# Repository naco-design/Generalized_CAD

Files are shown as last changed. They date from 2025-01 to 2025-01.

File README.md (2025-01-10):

# Generalized_CAD
Generalized CAD Assistant Device, This is a programmable macro pad!
\
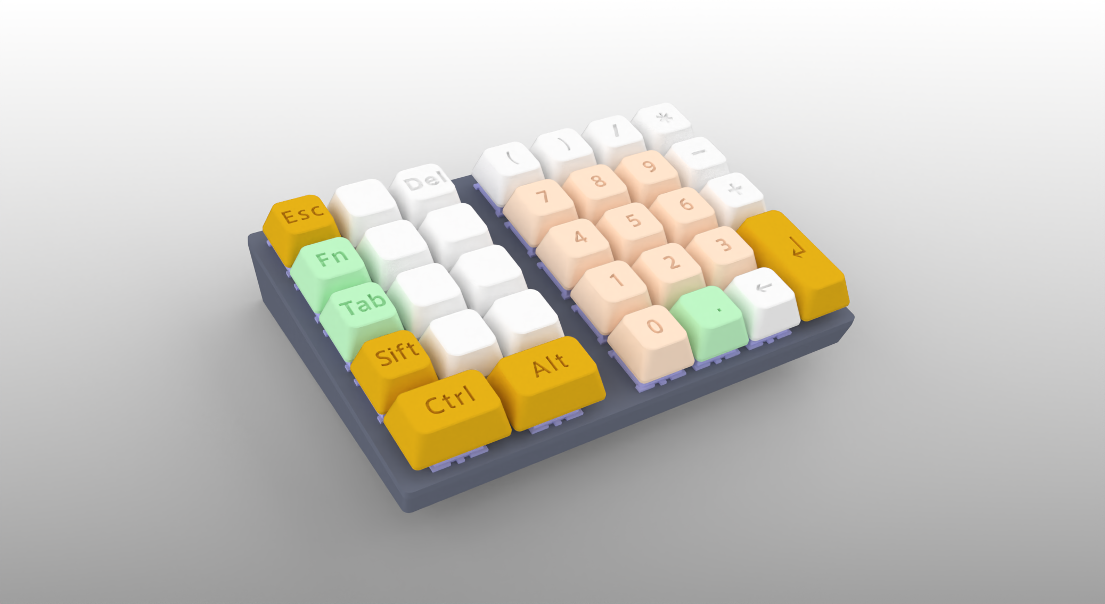
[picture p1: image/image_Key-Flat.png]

キーの上面がFlatになるデータの場合のイメージ

## 汎用型CAD（CADアシスタントデバイス）
CAD作業を行いやすくするための補助デバイス（マクロパッド）の制作データです。\
3Dプリントした部品とキースイッチやダイオード、ProMicro、WS2812などを組み合わせます。\
Vialに対応したファームウェアでキー設定をカスタマイズすることが可能です。
\
\
以下のデータを順次公開します。
* 3Dプリント用STLファイル（ケース、キーキャップ）
* VIAL対応ファームウェア
* 部品のリスト
* 回路の配線や組み立ての手順

## 開発にあたって
* 右手はマウスを握ったまま、左手で数値やショートカットを入力したい。
* 基盤をおこすのはハードルが高いので、回路は手配線で組む。
* カスタマイズしやすいように、3Dプリンターで製造したい。
* 大きさは、はがきサイズ（148*100mm）程度を目指す。

## 部品
### 3Dプリント用STL/STEPファイル（ケース、キーキャップ）
[ケース](Cases)\
Case_v2025-01.stl\
LED-Plate.stl\
ProMicro_Lock.stl\
BackPanel.stl\
レーザー加工の場合は BackPlate.ai\
\
[キーキャップ](Keycaps)\
キーの上面がFlatになるデータとStepになるデータがあります。\
\
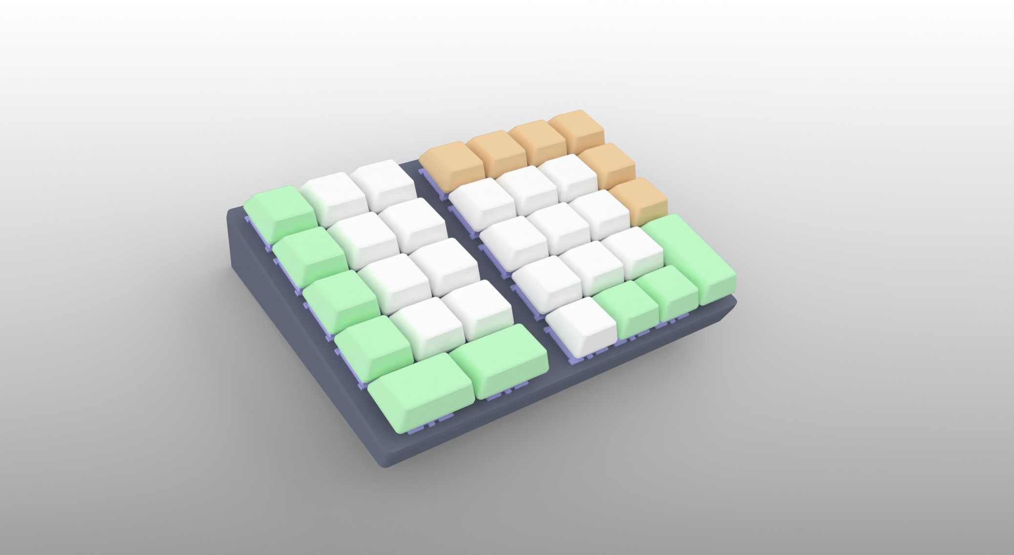
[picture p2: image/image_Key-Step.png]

キーの上面がStepになるデータの場合のイメージ

### 購入部品
参考としてAmazonの商品ページへのリンクも記載します。\
こちらで検証したものと同様の製品と思われるものを載せてはいますが、\
ロットや在庫などにより製品が異なるかもしれませんので注意してください。\
\
ProMicro ATmega32U4 USB-C [Amazon](https://www.amazon.co.jp/dp/B0B87D2FXZ)\
CherryMXと互換性のあるキースイッチ [Amazon](https://www.amazon.co.jp/dp/B0BYYWF14B)\
ダイオード [Amazon](https://www.amazon.co.jp/dp/B0BRQ5NNZS)\
WS2812のLEDテープ [Amazon](https://www.amazon.co.jp/dp/B088JWT7VT)\
タクトスイッチ [Amazon](https://www.amazon.co.jp/dp/B011XXVI80)\
配線用電線 [Amazon](https://www.amazon.co.jp/dp/B07GGZQXSF)\
熱圧入インサートナットM3 [Amazon](https://www.amazon.co.jp/dp/B09NNPWRH8)\
PC接続用USBケーブル [Amazon](https://www.amazon.co.jp/dp/B071D8THD2)\
クッションシール [Amazon](https://www.amazon.co.jp/dp/B01B4COI8W)

## 配線
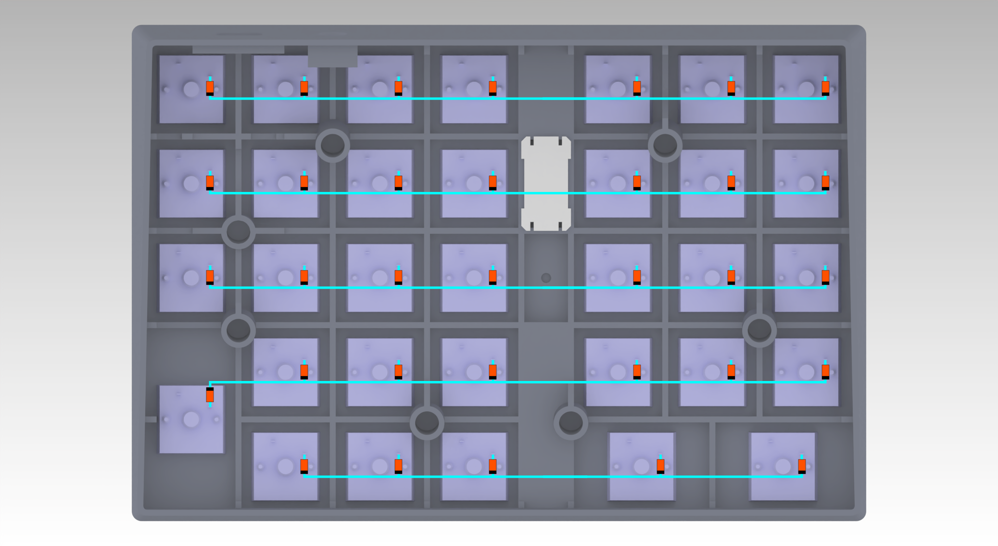
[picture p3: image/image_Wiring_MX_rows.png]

ダイオードの向きに注意して、キースイッチを横方向にハンダ付けして接続します。\
\
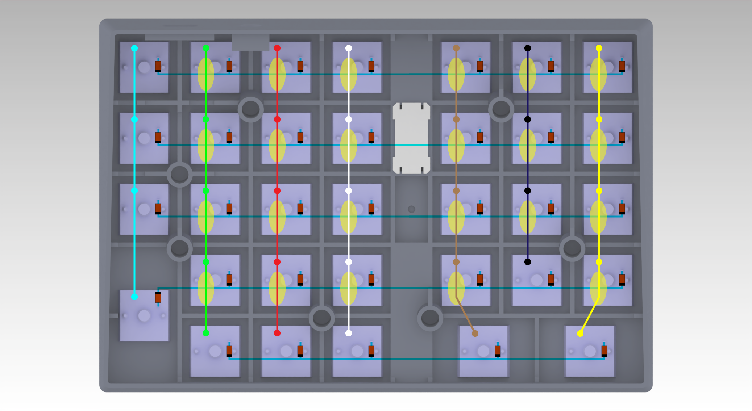
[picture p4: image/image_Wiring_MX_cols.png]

ショートしないように配慮しながら、キースイッチを縦方向にハンダ付けして接続します。\
\
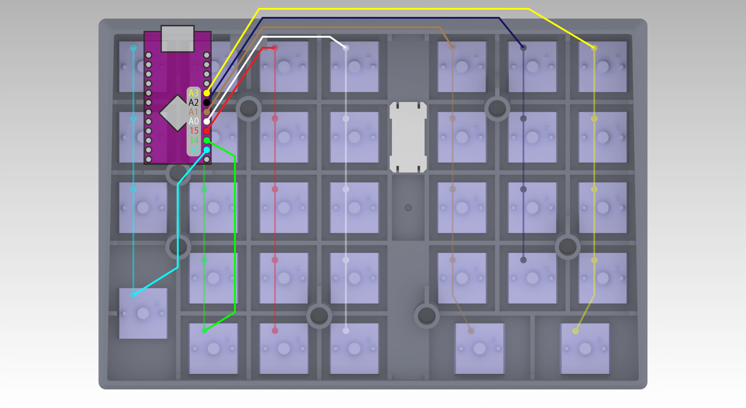
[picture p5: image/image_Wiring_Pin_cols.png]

縦方向の接続線をProMicroのピンにハンダ付けします。\
\
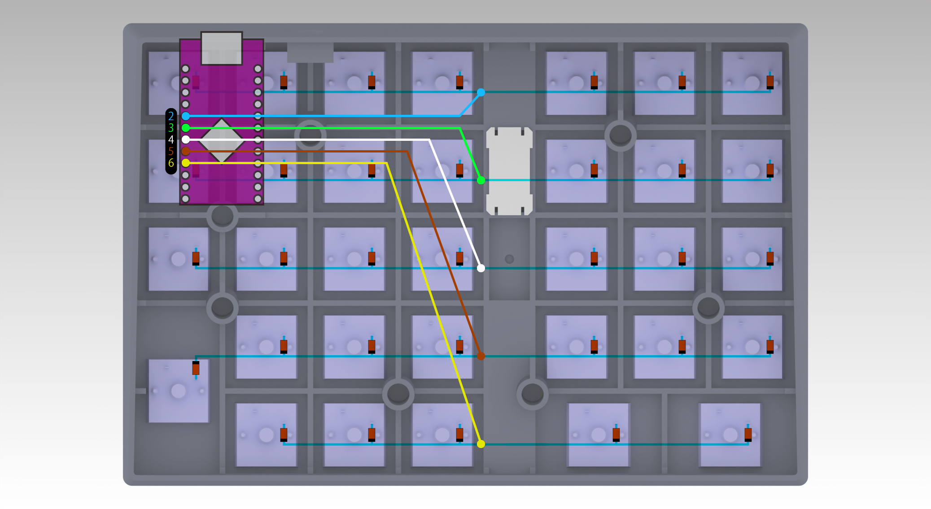
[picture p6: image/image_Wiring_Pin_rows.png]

横方向の接続線をProMicroのピンにハンダ付けします。\
\
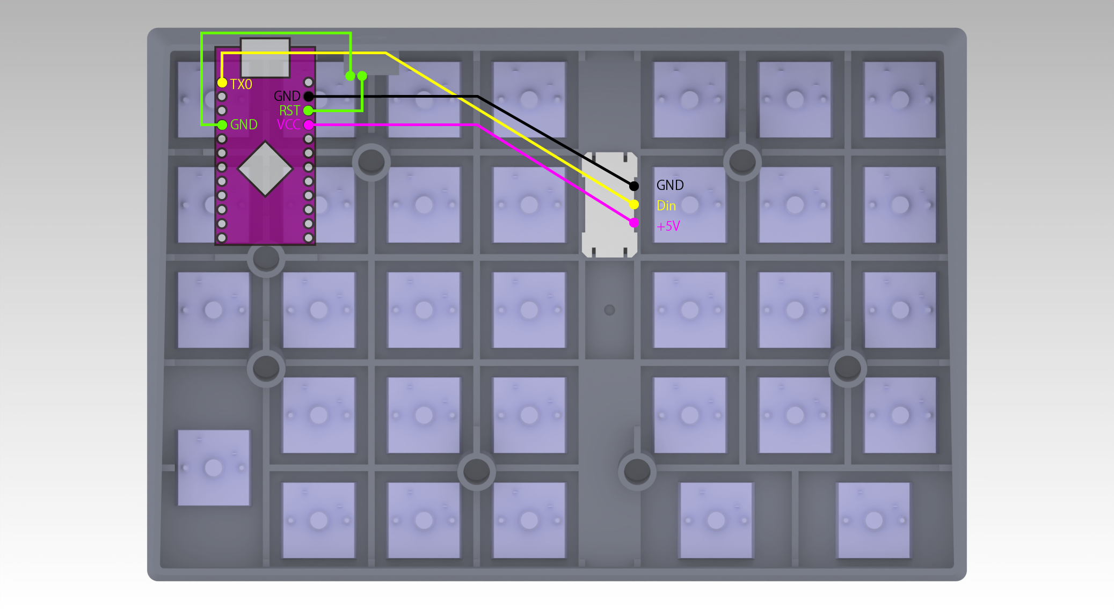
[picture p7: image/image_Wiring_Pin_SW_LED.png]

リセット用タクトスイッチとWS2812LEDをProMicroのピンにハンダ付けします。\
目視や配線を揺らしてみたりして部品が外れないかを確認します。\
回路部分は、テスターなどでショートや接続不良がないかなどを確認すると良いでしょう。

## ファームウェアの書き込み
[ファームウェア](Firmware)
コンパイル済みVial対応ファームウェア\
naco_design_generalized_cad_vial.hex　をダウンロードします。\
\
Chromeで　[Pro Micro Web Updaterのサイト](https://sekigon-gonnoc.github.io/promicro-web-updater/index.html) を開きます。\
「ファイルを選択」のボタンからnaco_design_generalized_cad_vial.hexを開き、flashボタンをクリックします。\
「対応したデバイスが見つかりませんでした。」と表示されますので、リセット用タクトスイッチを押します。\
Arduino Microがあらわれるので、接続をクリック。ファームウェアが書き込まれます。

## 動作確認やカスタマイズ
[Vialのサイト](https://get.vial.today/)を開き、Start Vial Webから動作の確認やキー設定の変更が行えます。

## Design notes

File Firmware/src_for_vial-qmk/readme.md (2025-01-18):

# generalized_cad

generalized_cad

*A short description of the keyboard/project*

* Keyboard Maintainer: [naco-design](https://github.com/naco-design)
* Hardware Supported: Pro Micro
* Hardware Availability: *Links to where you can find this hardware*

Make example for this keyboard (after setting up your build environment):

    make generalized_cad:default

Flashing example for this keyboard:

    make generalized_cad:default:flash

See the [build environment setup](https://docs.qmk.fm/#/getting_started_build_tools) and the [make instructions](https://docs.qmk.fm/#/getting_started_make_guide) for more information. Brand new to QMK? Start with our [Complete Newbs Guide](https://docs.qmk.fm/#/newbs).

## Bootloader

Enter the bootloader in 3 ways:

* **Bootmagic reset**: Hold down the key at (0,0) in the matrix (usually the top left key or Escape) and plug in the keyboard
* **Physical reset button**: Briefly press the button on the back of the PCB - some may have pads you must short instead
* **Keycode in layout**: Press the key mapped to `QK_BOOT` if it is available

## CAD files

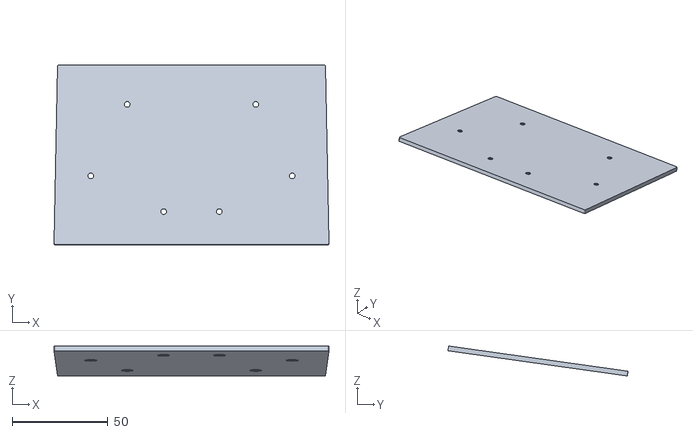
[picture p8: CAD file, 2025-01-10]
Cases/BackPanel.stl
143.3 x 93.9 x 15.6

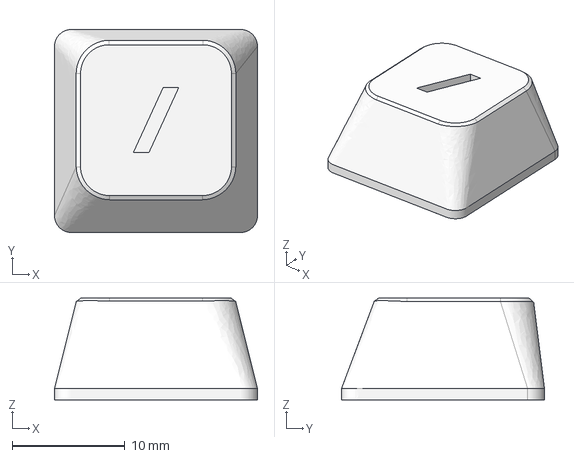
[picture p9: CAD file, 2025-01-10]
Keycaps/Flat/cap_sls.stp
18.0 x 18.0 x 9.00 mm

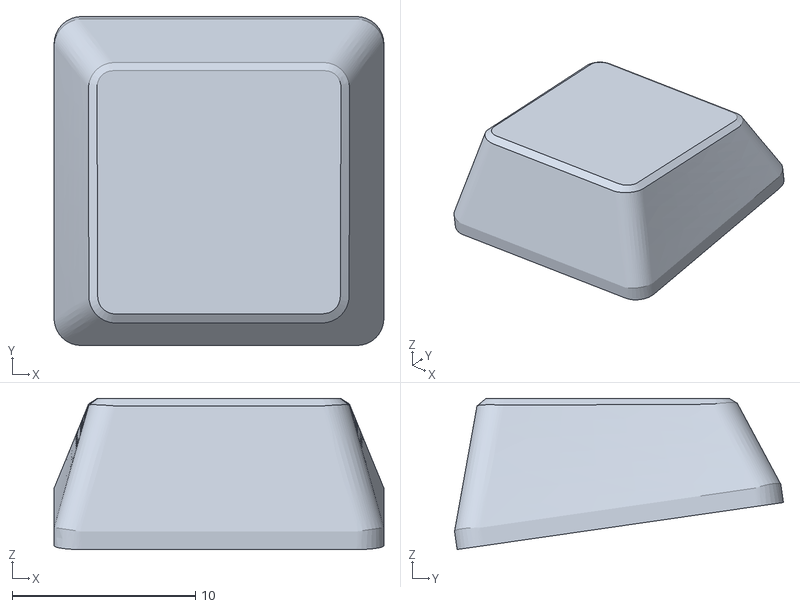
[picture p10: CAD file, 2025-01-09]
Keycaps/Step/KeyCap-Step_1U.stl
18.0 x 18.0 x 8.25

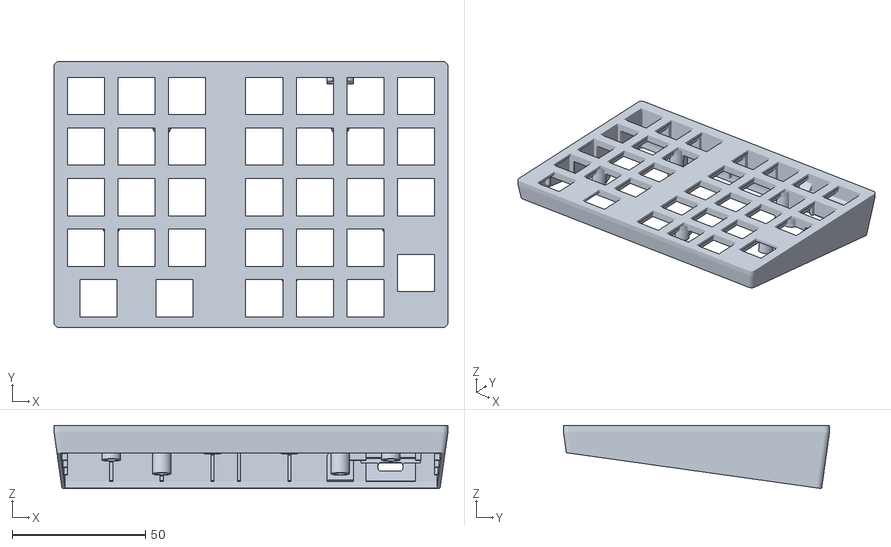
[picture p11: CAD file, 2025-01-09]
Cases/Case_v2025-01.stl
148.0 x 100.0 x 23.7

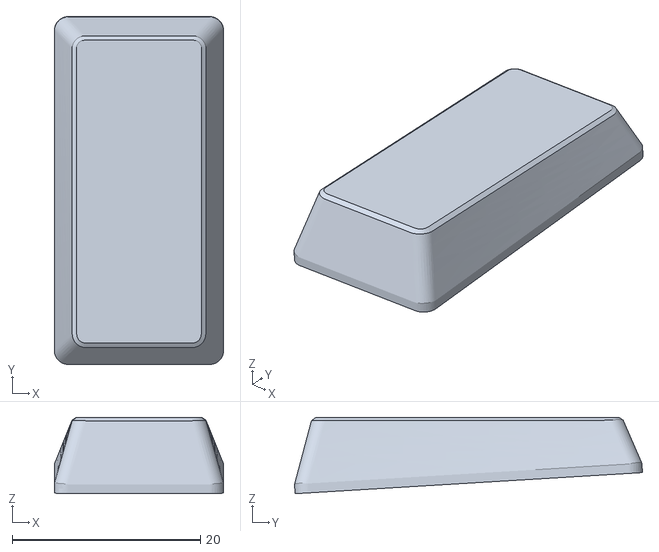
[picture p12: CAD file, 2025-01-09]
Keycaps/Step/KeyCap-Step_2U-H.stl
18.0 x 37.0 x 8.12

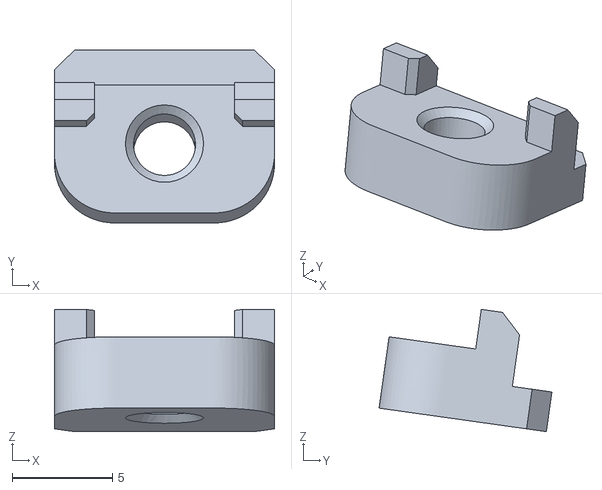
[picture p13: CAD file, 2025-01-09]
Cases/ProMicro_Lock.stl
11.0 x 8.64 x 6.11

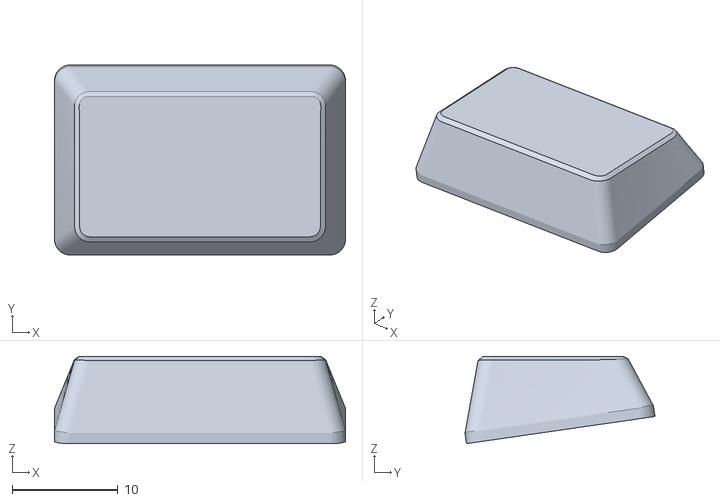
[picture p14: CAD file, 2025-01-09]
Keycaps/Step/KeyCap-Step_1_5U.stl
27.5 x 18.0 x 8.25

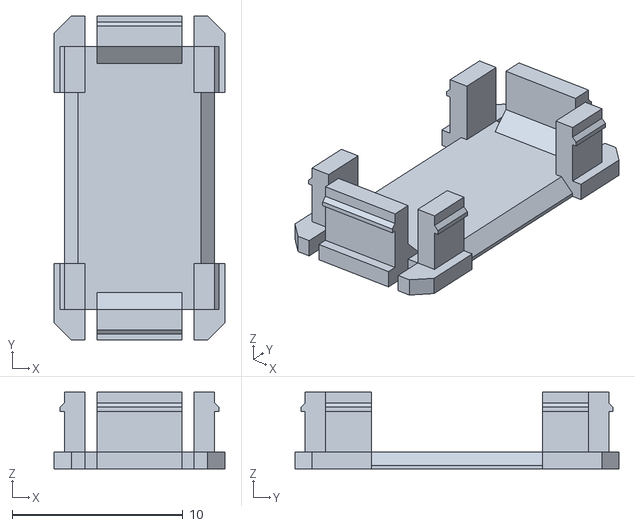
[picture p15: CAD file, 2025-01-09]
Cases/LED-Plate.stl
10.0 x 19.0 x 4.50

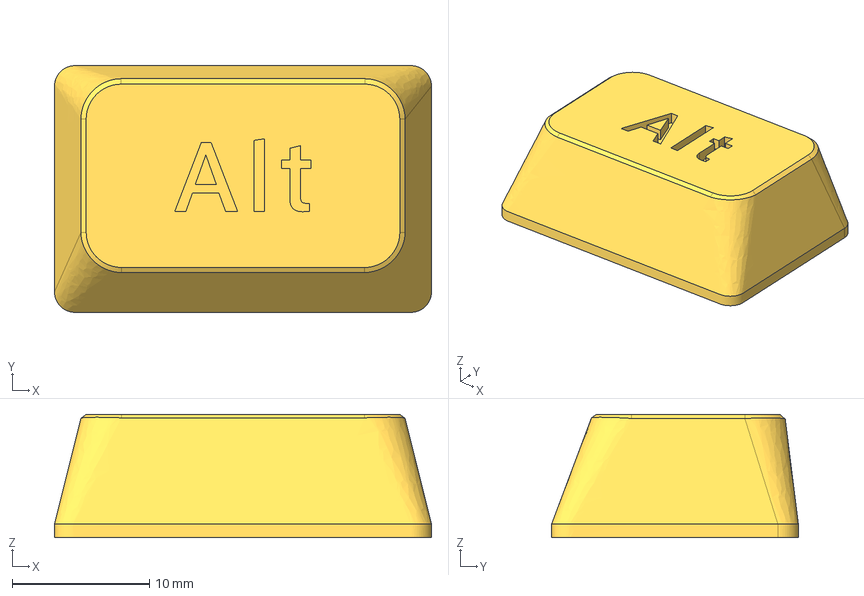
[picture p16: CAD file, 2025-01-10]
Keycaps/Flat/cap_Alt.stp
27.5 x 18.0 x 9.00 mm

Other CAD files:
Keycaps/Flat/cap_5.stp
Keycaps/Flat/cap_4.stp
Keycaps/Flat/cap_3.stp
Keycaps/Flat/cap_mns.stp
Keycaps/Flat/cap_bspc.stp
Keycaps/Flat/cap_Sift.stp
Keycaps/Flat/cap_pls.stp
Keycaps/Flat/cap_9.stp
Keycaps/Flat/cap_Ctrl.stp
Keycaps/Flat/1U.stp
Keycaps/Flat/1_5U.stp
Keycaps/Flat/2U-H.stp
Keycaps/Flat/cap_0.stp
Keycaps/Flat/cap_1.stp
Keycaps/Flat/cap_2.stp
Keycaps/Flat/cap_6.stp
Keycaps/Flat/cap_7.stp
Keycaps/Flat/cap_8.stp
Keycaps/Flat/cap_Del.stp
Keycaps/Flat/cap_E001.stp
Keycaps/Flat/cap_Ent.stp
Keycaps/Flat/cap_Esc.stp
Keycaps/Flat/cap_Fn.stp
Keycaps/Flat/cap_Tab.stp
Keycaps/Flat/cap_ast.stp
Keycaps/Flat/cap_dot.stp
Keycaps/Flat/cap_lprn.stp
Keycaps/Flat/cap_rprn.stp

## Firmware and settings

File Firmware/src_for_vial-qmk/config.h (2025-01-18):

// Copyright 2024 naco-design (@naco-design)
// SPDX-License-Identifier: GPL-2.0-or-later

#pragma once

#define TAPPING_TERM 200

/* ws2812 RGB LED */
#define WS2812_DI_PIN D3
#define RGBLED_NUM 1
#define RGBLIGHT_SLEEP

#ifdef RGBLIGHT_ENABLE
  #define RGBLIGHT_LAYERS
  #define RGBLIGHT_HUE_STEP 8
  #define RGBLIGHT_SAT_STEP 17
  #define RGBLIGHT_VAL_STEP 17
  #define RGBLIGHT_LIMIT_VAL 64
#endif

#ifdef MIDI_ENABLE
#   define MIDI_ADVANCED
#endif  //  MIDI_ENABLE

// Reduce firmware size
#undef LOCKING_SUPPORT_ENABLE
#undef LOCKING_RESYNC_ENABLE
#undef RGBLIGHT_ANIMATIONS
#undef RGBLIGHT_EFFECT_BREATHING
#undef RGBLIGHT_EFFECT_RAINBOW_MOOD
#undef RGBLIGHT_EFFECT_RAINBOW_SWIRL
#undef RGBLIGHT_EFFECT_SNAKE
#undef RGBLIGHT_EFFECT_KNIGHT
#undef RGBLIGHT_EFFECT_CHRISTMAS
#undef RGBLIGHT_EFFECT_STATIC_GRADIENT
#undef RGBLIGHT_EFFECT_RGB_TEST
#undef RGBLIGHT_EFFECT_ALTERNATING
#undef RGBLIGHT_EFFECT_TWINKLE

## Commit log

2025-01-09 FW , STL Upload
    [Case_v2025-01.stl, KeyCap-Step_1.5U.stl, KeyCap-Step_1U.stl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]
2025-01-09 Upload Wiring image
2025-01-09 Update README.md
    配線の説明を追加
2025-01-09 Update README.md
    画像リンクを修正
2025-01-10 Update README.md
    ファームウェアの書き込み手順を追加
2025-01-10 Backpanel, PartsList&Link, fix_FW_setting
    バックパネルのデータの追加
    部品リストの修正とリンクの追加
    ファームウェアの初期キー設定の変更
    [BackPanel.stl]
2025-01-10 Keycap-FLAT Upload
    [1U.stp, 1_5U.stp, 2U-H.stp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]
